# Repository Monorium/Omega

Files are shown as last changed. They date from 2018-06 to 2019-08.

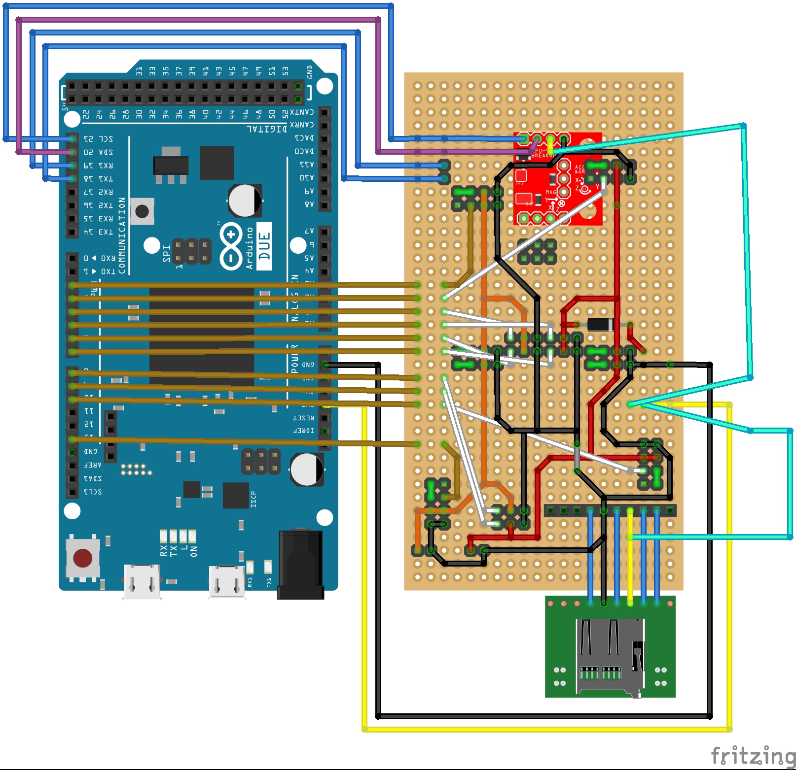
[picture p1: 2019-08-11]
Design/CircuitDesign/サーボ接続ボード.jpg

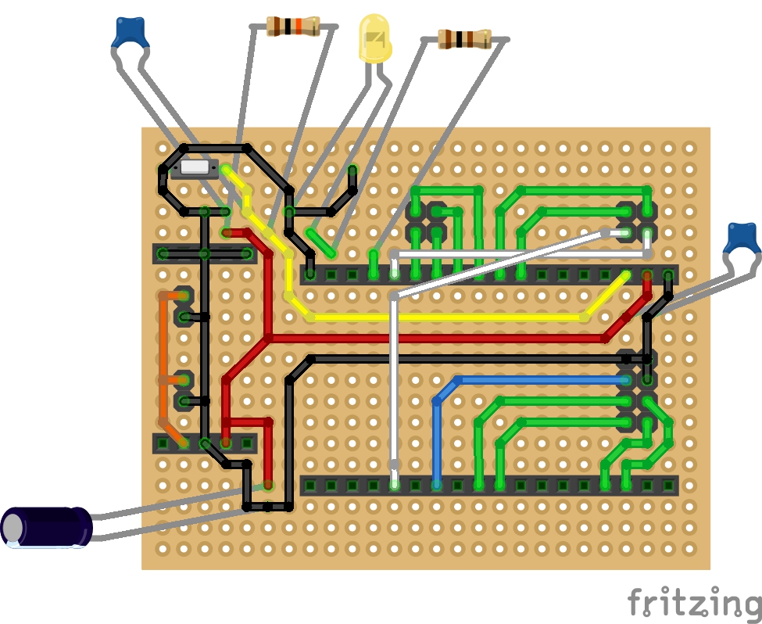
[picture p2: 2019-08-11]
Design/CircuitDesign/ESP32ボード.jpg

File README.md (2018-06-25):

# Omega
OmegaはAndroid端末で操作できる6足歩行の虫型ロボット（オモチャ）です。  
自分でゼロから作りたくなり、ハード設計からソフト開発まで勉強しながら気長に製作中です。

## リポジトリについて
完全に個人的なバージョン管理に使用しています。  
閲覧や再利用は自由ですが、利用したことによる不利益や損害など一切の責任を負いませんので了承願います。  

## 使用リソース
### 主要ハードウェア
* Arduino Due
* ESP-WROOM-32
* Android端末
### 設計ソフトウェア
* Fritzing
* PlantUML
* Inkscape
### ソフトウェア開発環境
* Visual Studio Code
* Arduino IDE
* Android Studio
### プラットフォームというか開発言語
* C++（Arduino）
* Micropython
* Cordova（with Onsen-UI）

## 実装機能（予定順に記載）
|タグ|機能|
|:-:|:--|
|-|サーボ個別制御（6個、Arduinoシリアル通信）|
|0.0.2|サーボ動作スピード制御|
|0.0.3|Wi-Fi通信|
|0.0.4|サーボ個別制御（全18個）|
|0.0.5|microSDでマスターデータ|
||16方向制御|
||左右回転制御|
||16方向と回転制御の複合|
||ポージング制御（Android側機能）|
||Android端末の傾きで16方向制御|
||ジャイロ搭載（Android端末の向きで回転制御）|
||カメラ搭載（Android端末でストリーミング再生）|
||VRカメラ搭載（このオモチャに乗るんです！！）|

## ライセンス
[MIT](https://github.com/Monorium/Omega/blob/master/LICENSE)です。

## 利用ライブラリ（決めたら必ず書きます）
* [ArduinoJson (Benoit BLANCHON)](https://github.com/bblanchon/ArduinoJson)
* [cordova-icon (Alex Disler)](https://github.com/AlexDisler/cordova-icon)
* [Cordovarduino (Xavier Seignard)](https://github.com/xseignard/cordovarduino)
* [MicroWebSrv (Jean-Christophe Bos & HC²)](https://github.com/jczic/MicroWebSrv)
* [QList (Martin Dagarin)](https://github.com/SloCompTech/QList)

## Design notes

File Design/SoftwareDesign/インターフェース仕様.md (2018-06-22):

# インターフェース仕様
## スマートフォン -> ESP32
_ソケットサーバであるESP32が、10秒間の無通信を検出すると、接続済みソケットをcloseする。_

* 通信方式：WebSocket
* 電文形式：JSON、ただしヘルスチェックは単純テキスト
* 電文の種類
    * 個別制御
    * 16方向＆旋回制御
    * 停止制御
    * 位置リセット
    * ヘルスチェック

### 個別制御
|項目|項目名|型|値|
|:--|:--|:-:|:--|
|制御区分|action|string|manual|
|制御速度|speed|int|1～255<sup>(*1)</sup>|
|対象サーボ|servo|array||
|- サーボID|id|int|0～17|
|- 角度|angle|int|0～180|

(*1)単位はpulse/15msec

ex)速度100で、0,2,17番目のサーボを全て90度に制御
```json
{
  "action":"manual",
  "speed":100,
  "servo":[
    {"id":0, "angle":90},
    {"id":2, "angle":90},
    {"id":17, "angle":90}
  ]
}
```

### 16方向＆旋回制御
|項目|項目名|型|値|
|:--|:--|:-:|:--|
|制御区分|action|string|auto|
|制御速度|speed|int|1～255<sup>(*1)</sup>|
|前方比率|forward|int|-100～100<br><sup>(*2)</sup><sup>(*3)</sup>|
|左方比率|left|int|-100～100<br><sup>(*3)</sup><sup>(*4)</sup>|
|旋回区分|turning|string|none<br>left<br>right|

(*2)正数は前方移動、負数は後方移動<br>
(*3)前方比率と左方比率のそれぞれの絶対値の合計は100であること<br>
(*4)正数は左方移動、負数は右方移動

ex)速度120で、北北東の方角へ、左旋回しながら移動
```json
{
  "action":"auto",
  "speed":120,
  "forward":75,
  "left":-25,
  "turning":"left"
}
```

### 停止制御
|項目|項目名|型|値|
|:--|:--|:-:|:--|
|制御区分|action|string|stop|

ex)サーボ制御を停止
```json
{
  "action":"stop"
}
```

### 位置リセット
|項目|項目名|型|値|
|:--|:--|:-:|:--|
|制御区分|action|string|reset|

ex)サーボの角度を初期値に戻して停止
```json
{
  "action":"reset"
}
```

### ヘルスチェック
テキスト「ping」をスマートフォンから送信すると、ESP32もテキスト「ping」を返送する。

---
## ESP32 -> Arduino Due
* 通信方式：シリアル1(115200bps)
* 電文形式：STX(0x02)+JSON+ETX(0x03)  
JSON部分の仕様は「スマートフォン->ESP32」と同じ。

---
## Arduino Due -> ESP32
* 通信方式：シリアル1(115200bps)
* 電文形式：STX(0x02)+JSON+ETX(0x03)

### サーボ制御
|項目|項目名|型|値|
|:--|:--|:-:|:--|
|制御区分|action|string|servo|
|対象サーボ|servo|array||
|- GPIO|pin|int||
|- 角度|angle|int|0～180|

ex)GPIO#2,5に接続されているサーボを全て80度に制御
```json
{
  "action":"servo",
  "servo":[
    {"pin":2, "angle":80},
    {"pin":5, "angle":80}
  ]
}
```

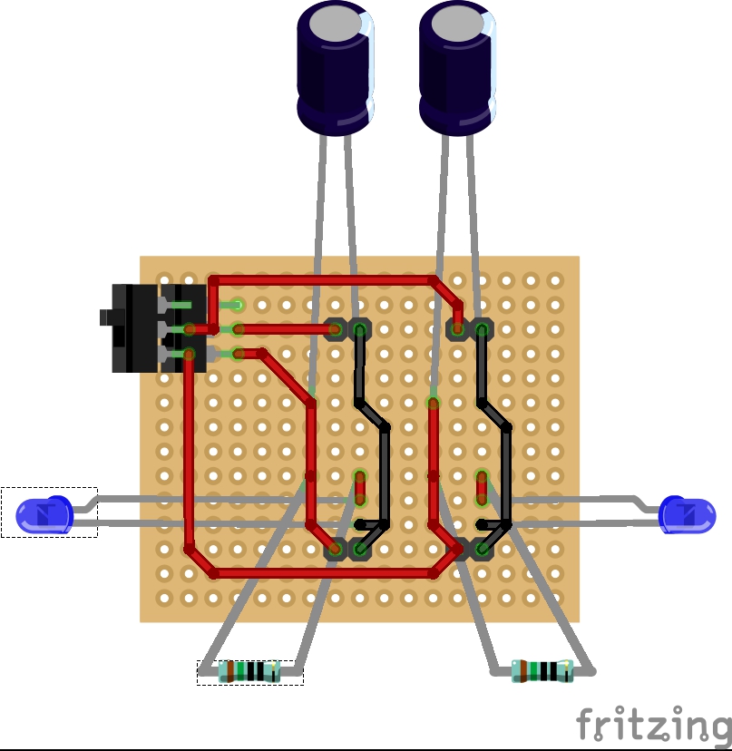
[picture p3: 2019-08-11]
Design/CircuitDesign/電源スイッチ.jpg

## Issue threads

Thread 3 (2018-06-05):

PWM制御が可能なPINの数

Monorium, 2018-06-05:
必要最低限のPWM制御PINは、サーボの数（18個）。
ArduinoDueは10個（PINの数は12個あるが2個は使えない）、ESP32は8個なので、余裕が無い。
今は問題ないが、追加機能でPWMが欲しくなると足りない。

Monorium, 2018-06-12:
### どのPINが使えないのか確認
12個（No.2～13）あるArduino DueのPWMを試しに同時制御してみた。

予想では、9と10が使えないはずだったのに、使えないのは **「11と12」**だった。つまり、Megaと同じ仕様ということか？

[Servoリファレンス](https://www.arduino.cc/en/Reference/Servo)

もう一度リファレンスを読んでみると、「_Megaでは12～23を使うと11と12は使えない_」とある。ということは、2～11の10個というパターンはいけるのか？

これなら、13を使わずに済むかも。

Monorium, 2018-06-22:
間違ってる、使えないのは11と12で間違いない。

Closed 2018-06-22.

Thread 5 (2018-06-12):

電源回路が貧弱

Monorium, 2018-06-12:
_課題にあげてなかったので追記。_

ESP32のソフト開発言語の決定に悩んでいたときの話。

ESP32用の3.3Vレギュレータが貧弱で、Wi-Fi接続しようとすると、いつも電圧不足で死ぬ。

起動時のドロップアウト電圧が大きいことが原因。

Monorium, 2018-06-12:
色々読みあさり、リニアテクノロジーの「LT1764AEQ-3.3」に決定。伴ってSMDに切り替え、各種コンデンサを買いたし。

ついでに5Vレギュレータも同じくリニアの「LT1529CQ-5」に変更。

回路を全面的に見直し。

Monorium, 2018-06-12:
届いたので、試しに組んでみたところ、非常に良い感じ♪

Monorium, 2018-06-17:
簡易版の電源回路は作成を完了。最終はプリント基板にしたい。
ボディに組み込んでみたところ、間違って11VをESP32に繋ぎ、ESP32が再起不能に。。

Monorium, 2018-06-17:
貧弱な点は解消したので、closeする。

Monorium, 2018-08-21:
18個のサーボを接続して少し負荷をかけただけで、煙が発生した。
どこから発生したかは未確認だが、恐らく配線だと思う。
- 電源回路とサーボ管理ボードの間
- サーボ管理ボード内のどこか

今後のためにも、何アンペア使ってるのか、実態を計測すべき。

Monorium, 2018-08-22:
バッテリーの線も不安。
せっかく二本並列に出てるのだから、二本接続に変更する。

Monorium, 2018-08-25:
アンペア計測。誤差はありそうだけど。
6本接地で0.4A
3本接地で0.6～0.9A ＆電圧低下
1本負荷かけて1.8A

歩行中は3本負荷になるから、単純計算では3.6A以上かな。
ギリギリ今のままでも行けそうだけど、煙が出たのが心配なので、電源回路を直すまでは負荷をかけないようにしようっと。

Monorium, 2018-09-25:
スイッチ部の制作を完了。
あまりテストしてないけど、大丈夫だろ、きっと。

Closed 2018-09-25.

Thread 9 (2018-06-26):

自分の重さを支えられず、サーボが脱力する

Monorium, 2018-06-26:
トルク4.6kgではダメなのか？
6V、6.5V、7Vで試してみるか。
それでダメならトルクの強いサーボに変更するしかないが、同じサイズじゃないと設計からやり直しになる。

Monorium, 2018-06-26:
6.6Vで、ギリギリ支えられそう。
Li-feバッテリーをサーボ専用に追加して、ついでにArduino用にしてしまえば、電源回路も簡易化できる。
買ってみるか。

Monorium, 2018-06-30:
Li-feが届いたので早速試験。
以下を確認。
- 6本の足で立っていられること
- 1本を地面から離せること
- 3.3Vレギュレータが熱くならないこと

でも、ちょっと力を加えたり、2本の足を上げたりすると、脱力しちゃう。やっぱりサーボの交換は必要だな。

Monorium, 2018-08-20:
第2間接のサーボ6個を交換。
ブラケットの作り直しをしていたので、時間がかかってしまったが、自重に負けずに立っていられるようになった。
でも、以下の課題はあり。
- ポーズによっては、ジリジリ音がある。
- 負荷をかけると、どこからか煙が出た。たぶん、電流が上がったことにより配線の許容範囲をこえてるのかも。

Monorium, 2018-08-26:
ブラケットの設計図のコミットも完了したので、この課題としてはcloseする。

Closed 2018-08-26.

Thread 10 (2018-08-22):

MicroSDCardReaderが破損

Monorium, 2018-08-22:
ArduinoのGNDに間違って6V流したときから、アクセスできなくなった。

Monorium, 2018-08-22:
Arduino側が破損したのか未確認。
まずは、esp32から接続してみて確認予定。

Monorium, 2018-08-26:
やっぱりSDカードリーダーが壊れたみたい。
esp32から繋いでも繋がらない。

Monorium, 2018-09-24:
電源回りの強化とともに、全体のボード設計を整理したら、接続できた。壊れてなかったみたい。配線ミスだったのかも。

新しいのは買っちゃったけどね。。

Closed 2018-09-24.

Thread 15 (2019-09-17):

サーボはやっぱり全部交換

Monorium, 2019-09-17:
6個だけトルクが強いサーボに交換して立つことは出来たけど、歩くことが困難。
制御でどうにかしようと思ったけど、そこに時間をかけるくらいなら、全交換でさっさと動かしたい。

Monorium, 2020-03-19:
交換は完了。
あとは動作確認。

Monorium, 2020-04-17:
まあまあな動き。
ボディが弱いのか、まだフニャフニャしてるけど、立てるようにはなった。
ボディを強化してみるかな。

Closed 2021-07-05.

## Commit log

2018-06-05 READMEを更新
2018-06-05 Feature/servo controll (#2)
    サーボ個別制御（6個、Arduinoシリアル通信）
    サーボ動作スピード制御
2018-06-08 Feature/wifi conn (#4)
    スマートフォンからWi-Fiでの制御を実装
2018-06-12 電源部（簡易版）の設計完了「
    [電源部（簡易版）.fzz]
2018-06-13 こだわりを捨てて配線を変更
    [電源部（簡易版）.fzz]
2018-06-22 Feature/servo control all (#6)
    16個のサーボをAndroidから操作できるように実装
    [servo.json]
2018-06-23 サーボの初回制御時にdutyを2回制御していたため、ぎこちない動きになっていた
2018-06-25 Feature/sdcard (#8)
    [servo.json]
2018-07-08 サーボブラケットの改良
2018-08-26 サーボ変更につき、ブラケットの形を変更
2018-10-06 サーボ電源の2系統化、接続関連の整理、とMicroSDスロットの実装、ジャイロセンサーの実装
    [ESP32ボード.fzz, サーボ接続ボード.fzz, 電源スイッチ.fzz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]
2019-02-17 サブモジュール化
2019-04-13 ソフトウェア設計の見直し issue#12
2019-04-13 簡易版かな？
    [Omega.fzz]
2019-08-11 設計の見直し issue#12
2020-01-02 やっぱりBodyはレーザーカッターで作りたいので準備
2020-01-03 やっぱりサーボホーンは2種類を実装
2020-02-08 レーザーカッター用に設計整理
2020-05-10 サーボ調整用ツールの作成
    [サーボ調整ツール.fzz]
